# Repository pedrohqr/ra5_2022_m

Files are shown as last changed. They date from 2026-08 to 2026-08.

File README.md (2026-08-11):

# RA5 2022 M — Base Board (Raptor)

Base/carrier board for a modular PLC (Programmable Logic Controller): an I/O
front-end with no main MCU of its own — sensing and metering peripherals are
driven by a separate MCU+LTE modem card that plugs into the onboard M.2
Key-E socket (`J1`, visible in the photos below). The socket follows the M.2
mechanical form factor but uses a custom pinout (native 3.3V logic) — it is
not meant to accept an off-the-shelf M.2 card. The pluggable MCU+modem card
itself now lives in its own separate repository, developed independently
from this base board.

Main blocks on this board:

- **Power**: input via the `B0303S-1W` isolated DC-DC module, `TPS54202DDC`
  buck regulator, `AMS1117-3.3` linear regulator (USB rail), and a USB-C
  connector that passes through to `J1` for flashing/debugging the plugged-in
  MCU card.
- **2x differential 4-20mA analog inputs** via an `ADS1115` I2C ADC.
- **2x digital inputs and 2x digital outputs**, opto/divider-conditioned and
  transistor-driven respectively.
- **`ATM90E32AS` three-phase energy meter**, in a galvanically isolated
  domain (`GND2`/`VDD2`) from the rest of the board, bridged via the
  `ISO7741N1-Y` digital isolator (SPI) and a `CS817X20LS`-family isolator
  (power-mode select).
- **`STM8S003F3P` housekeeping MCU**, reading/driving the digital I/O signals
  and intended to expose them over the shared I2C bus on `J1`.
- `KF250-3.5-2P-2` screw terminals for the current loops and other
  field-side connections.

## Renders of the finished board

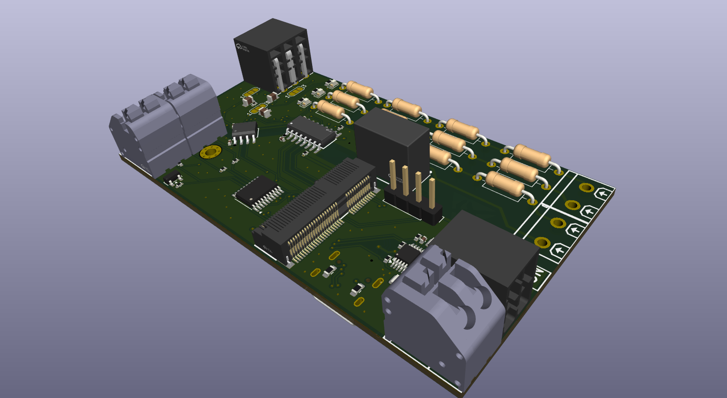
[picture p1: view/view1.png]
Board view 1

*Component-side view: the M.2 socket (`J1`) in the center, screw terminals
and field connectors along the edges, and the row of MOVs/varistors feeding
the energy-meter current inputs.*

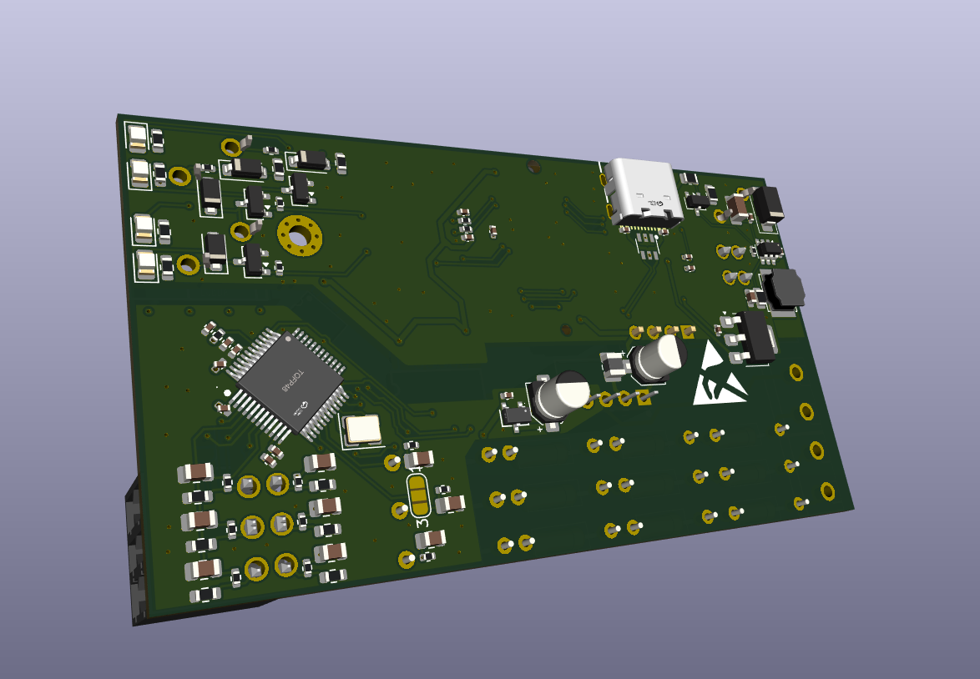
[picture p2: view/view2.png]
Board view 2

*Same side, rotated ~180°, showing the USB-C connector, the STM8
housekeeping MCU, and the power section.*

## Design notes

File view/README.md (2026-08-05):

# RA5 2022 M — Placa Base (Raptor)

Placa base/carrier de um CLP (Controlador Lógico Programável) modular: um
front-end de I/O que não tem MCU principal próprio — os periféricos de
sensoriamento e medição são controlados por um cartão MCU+modem LTE plugado
no soquete M.2 Key-E (`J1`, visível nas fotos), seguindo o padrão mecânico
M.2 mas com pinagem própria (3.3V nativo, sem relação com um cartão M.2 real).

Principais blocos presentes na placa:

- **Alimentação**: entrada via módulo `B0303S-1W`, buck `TPS54202DDC`,
  regulador linear `AMS1117-3.3` (trilho USB) e conector USB-C de
  passthrough para flash/debug do cartão MCU.
- **2x entradas analógicas 4-20mA** (diferenciais) via ADC `ADS1115`.
- **2x entradas e 2x saídas digitais** condicionadas por opto/divisor e
  transistor, respectivamente.
- **Medidor de energia trifásico `ATM90E32AS`**, em domínio galvanicamente
  isolado (`GND2`/`VDD2`) do resto da placa.
- **MCU de housekeeping `STM8S003F3P`**, fazendo a ponte I2C dos sinais de
  I/O digital.
- Terminais parafusáveis `KF250-3.5-2P-2` para os laços de corrente e
  demais conexões de campo.

## Renders da placa finalizada

Vista 1 da placa
*Vista geral do lado dos componentes: soquete M.2 (`J1`), USB-C, terminais
parafusáveis e conectores de campo nas laterais.*

Vista 2 da placa
*Vista girada ~180°, mostrando o mesmo lado a partir do ângulo oposto.*

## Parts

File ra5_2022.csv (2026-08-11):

Reference | Qty | Value | DNP | Exclude from BOM | Exclude from Board | Footprint | JLCPCB Part #
C1 | 1 | 10uF |  |  |  | Capacitor_SMD:C_1206_3216Metric | C13585
C2,C4,C10,C12,C14,C15,C16,C18,C19,C20,C21,C23,C37,C38,C39,C40 | 16 | 100nF |  |  |  | Capacitor_SMD:C_0402_1005Metric | C1525,C307331
C5,C41 | 2 | 10uF |  |  |  | Capacitor_SMD:CP_Elec_4x5.4 | C22383768
C6,C7 | 2 | 22uF |  |  |  | Capacitor_SMD:C_0603_1608Metric | C59461
C8,C11,C13,C22,C42 | 5 | 10uF |  |  |  | Capacitor_SMD:C_0402_1005Metric | C15525
C9 | 1 | 56pF |  |  |  | Capacitor_SMD:C_0603_1608Metric | C39148
C17 | 1 | 1uF |  |  |  | Capacitor_SMD:C_0402_1005Metric | C52923
C24,C25,C26,C27,C28,C29,C31,C32,C33,C34,C35,C36 | 12 | 33nF |  |  |  | Capacitor_SMD:C_0805_2012Metric | C1739
C30 | 1 | 4.7uF |  |  |  | Capacitor_SMD:C_0402_1005Metric | C23733
CN1,CN3,CN4 | 3 | KF250-3.5-2P-2 |  |  |  | ra5_2022:CONN-TH_P3.50_KF250-3.5-2P-2 | C475163
CN2 | 1 | MX15EDGRHC-3.5-2*02P-BK01-CU-A |  |  |  | ra5_2022:CONN-TH_4P-P3.50_JL15EDGRHC-35002B01 | C49142488
D1 | 1 | SS210 |  |  |  | Diode_SMD:D_SMA | C14996
D2,D9,D11,D13,D15 | 5 | LED |  |  |  | LED_SMD:LED_0805_2012Metric | C19171391
D3 | 1 | USBLC6-2SC6 |  |  |  | ra5_2022:SOT-23-6_L2.9-W1.6-P0.95-LS2.8-BL | C7519
D4,D5,D6 | 3 | LED |  |  |  | LED_SMD:LED_0603_1608Metric | C2994781
D7,D8 | 2 | 1N5819WS |  |  |  | Diode_SMD:D_SOD-323 | C191023
D10,D14 | 2 | BZT52C3V3 |  |  |  | Diode_SMD:D_SOD-123 | C216707
D12,D16 | 2 | 1N4004W |  |  |  | Diode_SMD:D_SOD-123F | C162734
J1 | 1 | Bus_M.2_Socket_E |  |  |  | ra5_2022:CONN-SMD_AS0BC21-S48BE-7H | C410527
J3 | 1 | MX15EDGRHC-3.5-2*03P-BK01-Cu-A |  |  |  | ra5_2022:MX15EDGRHC-3.5-2x03P | C49142489
J4 | 1 | MX15EDGKNH-3.5-2*03P-BK01-Cu-A |  |  | Excluded from board |  | C49142469
L1 | 1 | 6.8uH |  |  |  | Inductor_SMD:L_1008_2520Metric | C48533097
L2 | 1 | 10uH |  |  |  | ra5_2022:IND-SMD_L5.0-W5.0-1 | C182189
Q1,Q2,Q3,Q4,Q5 | 5 | BC817-25 |  |  |  | Package_TO_SOT_SMD:SOT-23 | C20069154
R1,R2,R4 | 3 | 100k |  |  |  | Resistor_SMD:R_0805_2012Metric | C149504
R3 | 1 | 150R |  |  |  | Resistor_SMD:R_0603_1608Metric | C22808
R5 | 1 | 22k |  |  |  | Resistor_SMD:R_0402_1005Metric | C25768
R6,R9 | 2 | 4.7k |  |  |  | Resistor_SMD:R_0402_1005Metric | C25900
R7,R8 | 2 | 5.1k |  |  |  | Resistor_SMD:R_0603_1608Metric | C384321
R10,R11 | 2 | 100R |  |  |  | Resistor_SMD:R_0402_1005Metric | C25076
R12,R13,R14,R15,R16,R17,R18,R19,R20,R21,R22,R23 | 12 | 120k |  |  |  | Resistor_THT:R_Axial_DIN0207_L6.3mm_D2.5mm_P10.16mm_Horizontal | C119370
R33,R34,R35,R36,R37,R38,R45,R46,R47,R48,R49,R50,R51,R52 | 14 | 1k |  |  |  | Resistor_SMD:R_0402_1005Metric | C11702
R39,R40,R41,R42,R43,R44 | 6 | 2.4R |  |  |  | Resistor_SMD:R_0603_1608Metric | C2998116
R55,R56,R57,R60,R64,R65,R67,R71,R72,R74 | 10 | 10k |  |  |  | Resistor_SMD:R_0402_1005Metric | C25744
R58,R59 | 2 | 100R |  |  |  | Resistor_SMD:R_1206_3216Metric | C17901
R61,R66,R68,R73,R75,R76,R77 | 7 | 270R |  |  |  | Resistor_SMD:R_0603_1608Metric | C22966
R62,R69 | 2 | 39k |  |  |  | Resistor_SMD:R_0603_1608Metric | C23153
U1 | 1 | STM8S003F3P |  |  |  | Package_SO:TSSOP-20_4.4x6.5mm_P0.65mm | C52717
U2 | 1 | TPS54202DDC |  |  |  | Package_TO_SOT_SMD:SOT-23-6 | C191884
U3 | 1 | B0303S-1WR2 |  |  |  | ra5_2022:PWRM-TH_BXXXXS-1WR2 | C7598619
U4 | 1 | XC6206P332MR-JSM |  |  |  | ra5_2022:SOT-23-3_L3.0-W1.7-P0.95-LS2.9-BR | C20616640
U5 | 1 | ISO7741N1-Y |  |  |  | ra5_2022:SOIC-16_L9.9-W3.9-P1.27-LS6.0-BL-1 | C53446593
U6 | 1 | CA-IS3720CLS |  |  |  | ra5_2022:SOIC-8_L4.9-W3.9-P1.27-LS6.0-BL | C41784134
U7 | 1 | AMS1117-3.3 |  |  |  | Package_TO_SOT_SMD:SOT-223-3_TabPin2 | C50313802
U8,U9 | 2 | DB126V-5.0-2P-BK-P |  |  |  | ra5_2022:CONN-TH_2P-P5.00_DIBO_DB126V-5.0-2P-BU-P | C49260677
U10 | 1 | ATM90E32AS-AU-R |  |  |  | ra5_2022:TQFP-48_L7.0-W7.0-P0.50-LS9.0-BL | C177153
U12 | 1 | ADS1115IDGS |  |  |  | Package_SO:TSSOP-10_3x3mm_P0.5mm | C37593
USB1 | 1 | HYCW498-USBC16-735B |  |  |  | ra5_2022:USB-C-SMD_HYCW498-USBC16-735B | C42400252
Y1 | 1 | ABM8G-16.384MHZ-18-D2Y-T |  |  |  | Crystal:Crystal_SMD_3225-4Pin_3.2x2.5mm | C7065080

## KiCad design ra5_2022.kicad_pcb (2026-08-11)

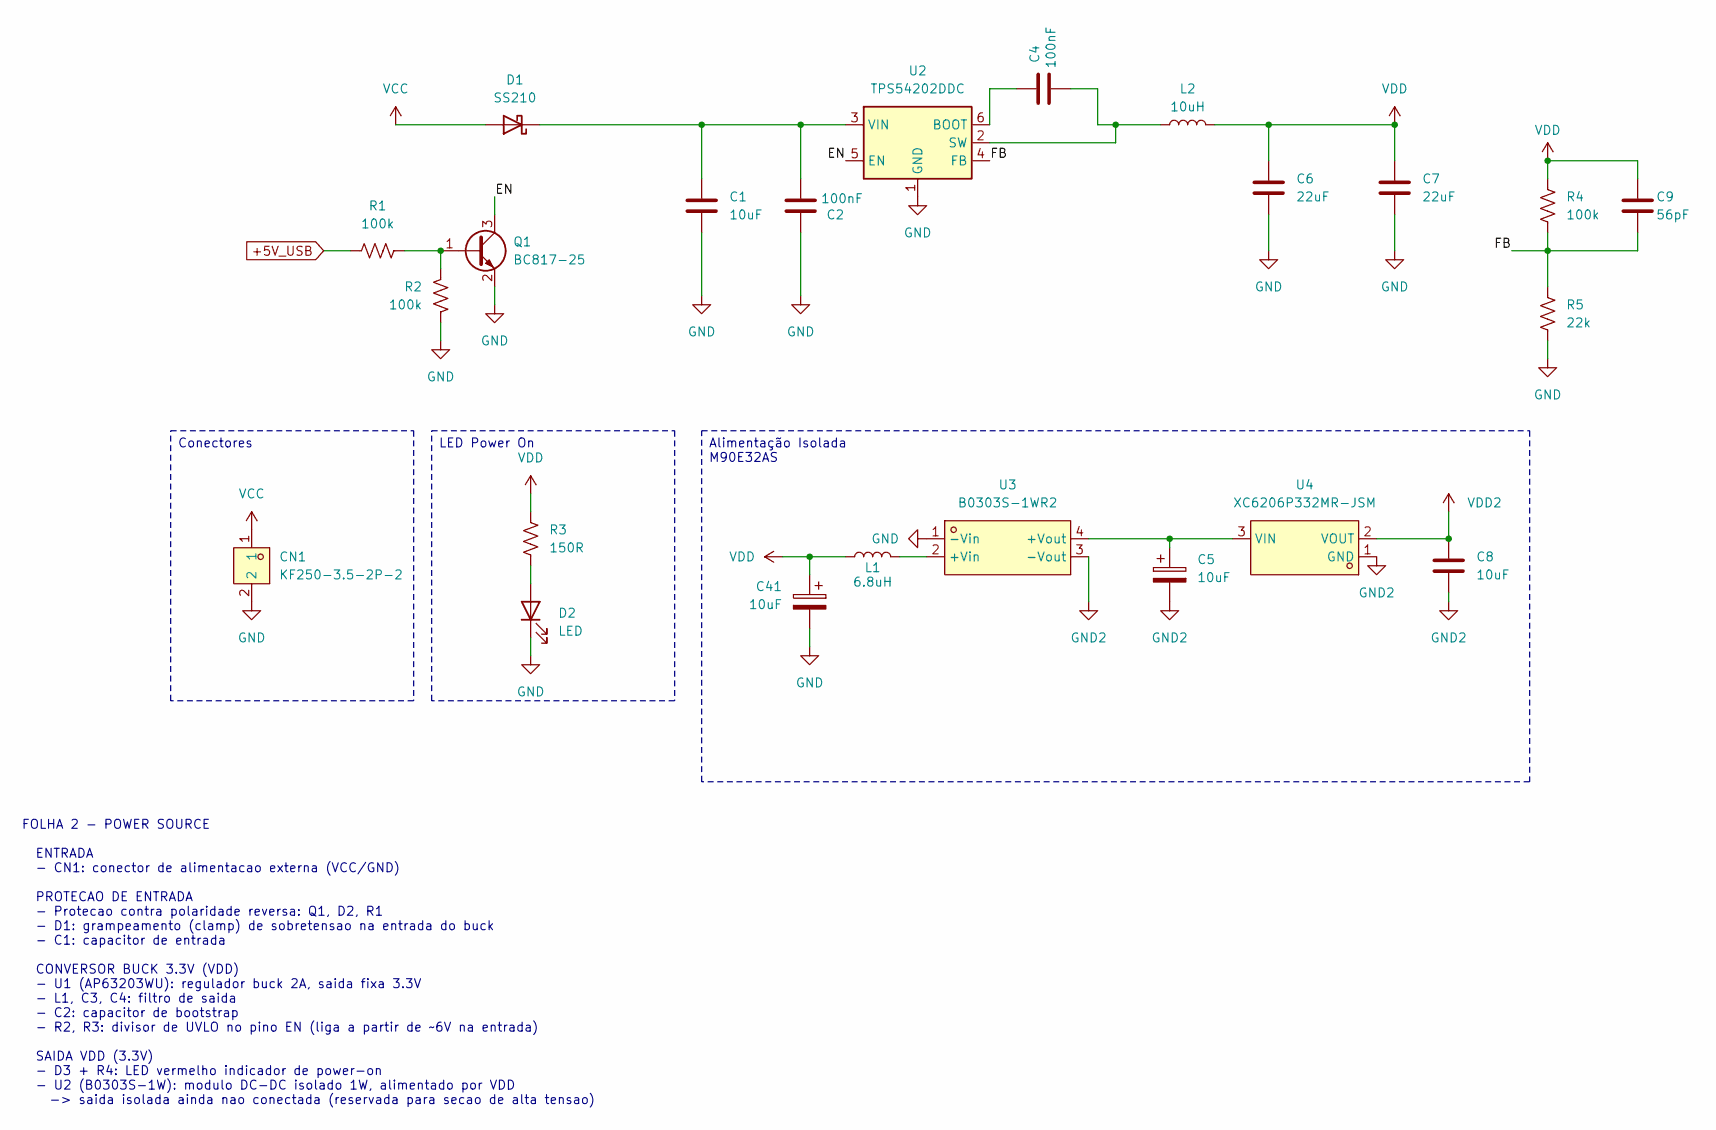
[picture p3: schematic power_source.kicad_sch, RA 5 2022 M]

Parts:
C1: 10uF; C_1206_3216Metric; MPN CL31A106KBHNNNE; JLCPCB Part # C13585
C2: 100nF; C_0402_1005Metric; MPN CL05B104KB54PNC; JLCPCB Part # C307331
C4: 100nF; C_0402_1005Metric; MPN CL05B104KO5NNNC; JLCPCB Part # C1525
C5, C41: 10uF; CP_Elec_4x5.4; MPN VT1E100M0405; JLCPCB Part # C22383768
C6, C7: 22uF; C_0603_1608Metric; MPN CL10A226MQ8NRNC; JLCPCB Part # C59461
C8: 10uF; C_0402_1005Metric; MPN CL05A106MQ5NUNC; JLCPCB Part # C15525
C9: 56pF; C_0603_1608Metric; MPN CL10C560JB8NNNC; JLCPCB Part # C39148
CN1: KF250-3.5-2P-2; CONN-TH_P3.50_KF250-3.5-2P-2; MPN KF250-3.5-2P-2; JLCPCB Part # C475163
D1: SS210; D_SMA; MPN SS210; JLCPCB Part # C14996
D2: LED; LED_0805_2012Metric; MPN YLED0805R; JLCPCB Part # C19171391
L1: 6.8uH; L_1008_2520Metric; MPN SLW252010S6R8MST; JLCPCB Part # C48533097
L2: 10uH; IND-SMD_L5.0-W5.0-1; MPN SLW5040S100MST; JLCPCB Part # C182189
Q1: BC817-25; SOT-23; MPN BC817-25; JLCPCB Part # C20069154
R1, R2, R4: 100k; R_0805_2012Metric; MPN 0805W8F1003T5E; JLCPCB Part # C149504
R3: 150R; R_0603_1608Metric; MPN 0603WAF1500T5E; JLCPCB Part # C22808
R5: 22k; R_0402_1005Metric; MPN 0402WGF2202TCE; JLCPCB Part # C25768
U2: TPS54202DDC; SOT-23-6; MPN TPS54202DDCR; JLCPCB Part # C191884
U3: B0303S-1WR2; PWRM-TH_BXXXXS-1WR2; MPN B0303S-1WR2; JLCPCB Part # C7598619
U4: XC6206P332MR-JSM; SOT-23-3_L3.0-W1.7-P0.95-LS2.9-BR; MPN XC6206P332MR-JSM; JLCPCB Part # C20616640

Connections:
+5V_USB: R1.1; also elsewhere on the board
/Power Source/EN: Q1.3 (C), U2.5 (EN)
/Power Source/FB: C9.2, R4.1, R5.1, U2.4 (FB)
GND: C1.2, C2.1, C6.2, C7.2, C41.2, CN1.2, D2.1 (K), Q1.2 (E), R2.1, R5.2, U2.1 (GND), U3.1 (-Vin); also elsewhere on the board
GND2: C5.2, C8.2, U3.3 (-Vout), U4.1 (GND); also elsewhere on the board
unnamed: C1.1, C2.2, D1.1 (K), U2.3 (VIN)
unnamed: D2.2 (A), R3.2
unnamed: Q1.1 (B), R1.2, R2.2
unnamed: C4.1, U2.6 (BOOT)
unnamed: C4.2, L2.1, U2.2 (SW)
unnamed: L1.2, U3.2 (+Vin)
unnamed: C5.1, U3.4 (+Vout), U4.3 (VIN)
VCC: CN1.1, D1.2 (A)
VDD: C6.1, C7.1, C9.1, C41.1, L1.1, L2.2, R3.1, R4.2; also elsewhere on the board
VDD2: C8.1, U4.2 (VOUT); also elsewhere on the board

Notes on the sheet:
FOLHA 2 - POWER SOURCE ENTRADA - CN1: conector de alimentacao externa (VCC/GND) PROTECAO DE ENTRADA - Protecao contra polaridade reversa: Q1, D2, R1 - D1: grampeamento (clamp) de sobretensao na entrada do buck - C1: capacitor de entrada CONVERSOR BUCK 3.3V (VDD) - U1 (AP63203WU): regulador buck 2A,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
Conectores
Alimentação Isolada M90E32AS
LED Power On

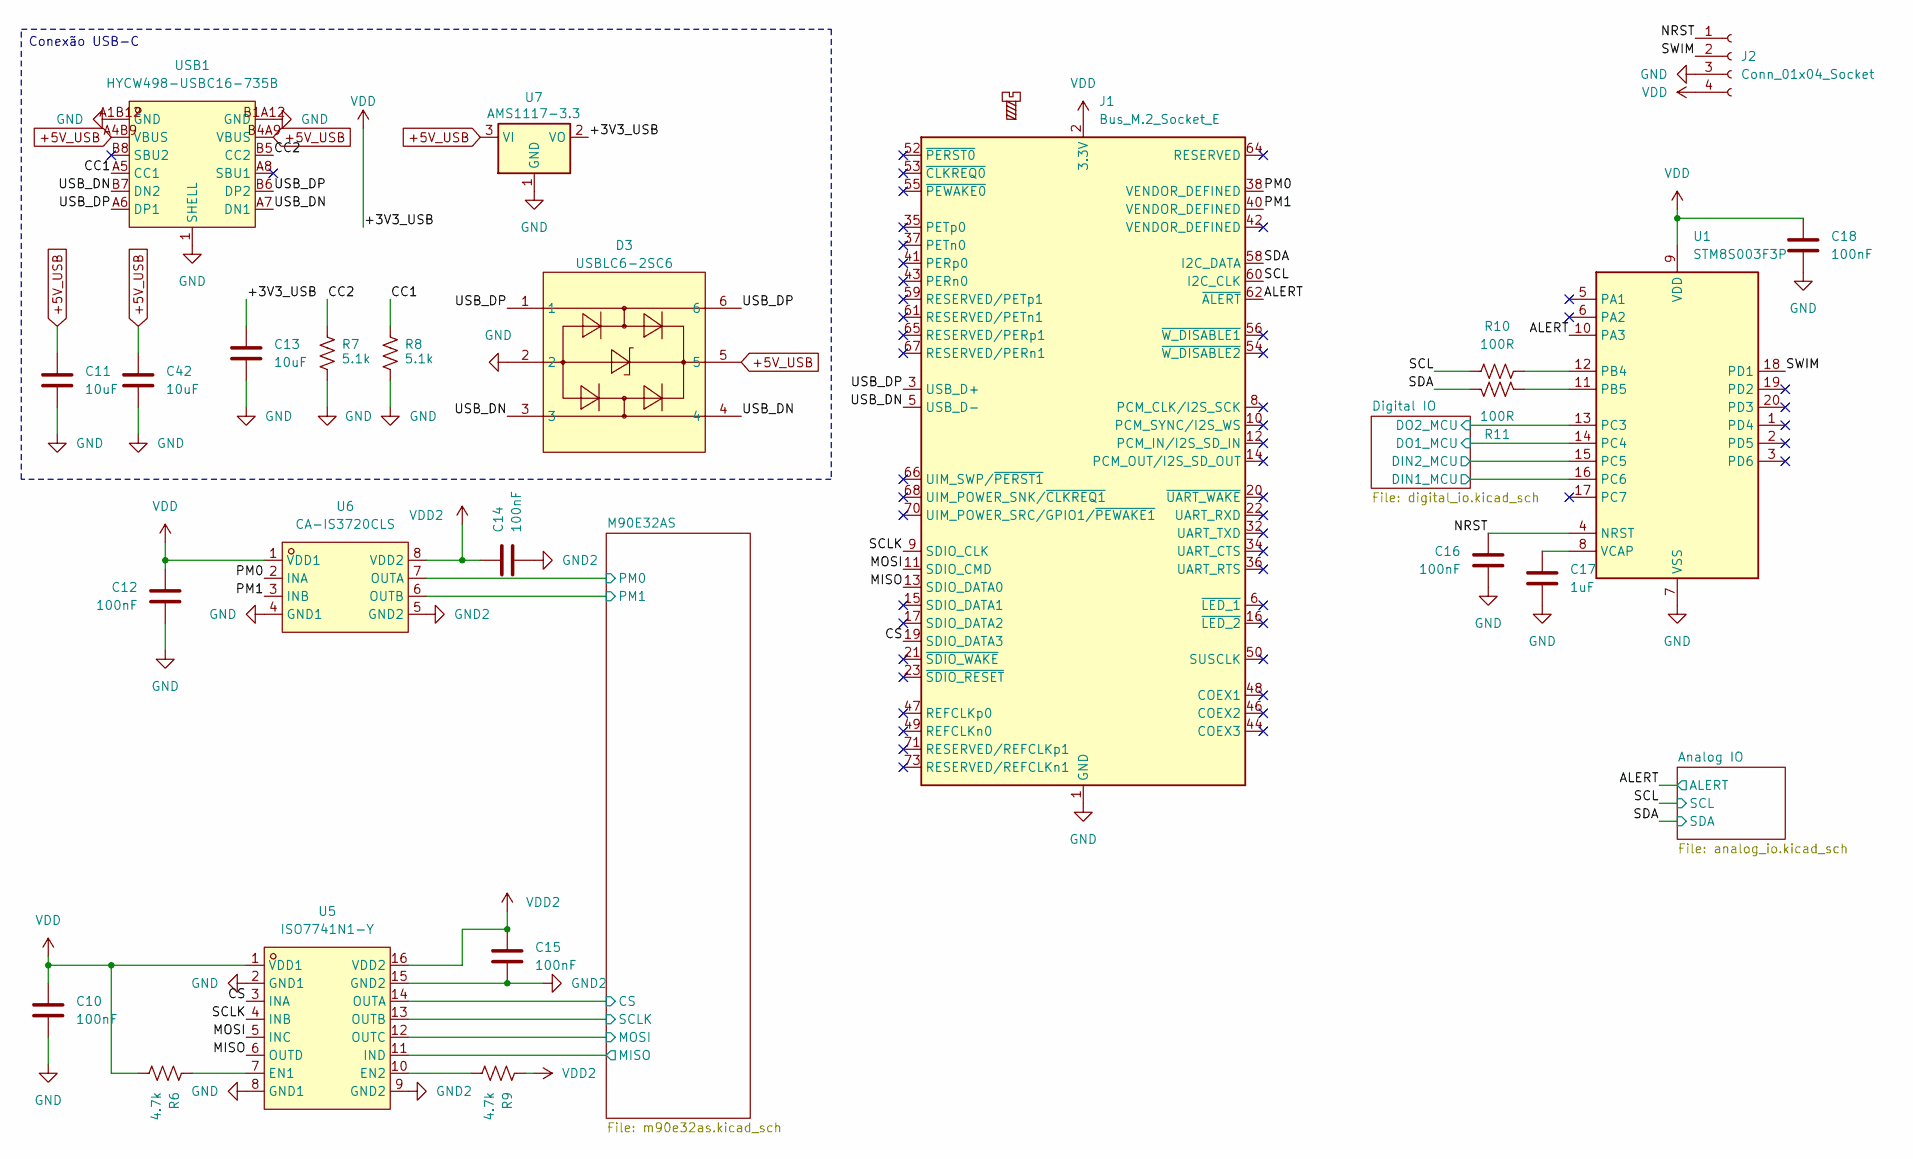
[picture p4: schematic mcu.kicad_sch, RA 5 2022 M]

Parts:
C10, C12, C14, C15, C16, C18: 100nF; C_0402_1005Metric; MPN CL05B104KO5NNNC; JLCPCB Part # C1525
C11, C13, C42: 10uF; C_0402_1005Metric; MPN CL05A106MQ5NUNC; JLCPCB Part # C15525
C17: 1uF; C_0402_1005Metric; MPN CL05A105KA5NQNC; JLCPCB Part # C52923
D3: USBLC6-2SC6; SOT-23-6_L2.9-W1.6-P0.95-LS2.8-BL; MPN USBLC6-2SC6; JLCPCB Part # C7519
H1: MountingScrew; MountingHole_2.2mm_M2_Pad_Via
J1: Bus_M.2_Socket_E; CONN-SMD_AS0BC21-S48BE-7H; MPN AS0BC21-S40BE-7H; JLCPCB Part # C410527
J2: Conn_01x04_Socket; PinHeader_1x04_P2.54mm_Vertical
R6, R9: 4.7k; R_0402_1005Metric; MPN 0402WGF4701TCE; JLCPCB Part # C25900
R7, R8: 5.1k; R_0603_1608Metric; MPN WR04X512JTL; JLCPCB Part # C384321
R10, R11: 100R; R_0402_1005Metric; MPN 0402WGF1000TCE; JLCPCB Part # C25076
U1: STM8S003F3P; TSSOP-20_4.4x6.5mm_P0.65mm; MPN STM8S003F3P6TR; JLCPCB Part # C52717
U5: ISO7741N1-Y; SOIC-16_L9.9-W3.9-P1.27-LS6.0-BL-1; MPN ISO7741N1-Y; JLCPCB Part # C53446593
U6: CA-IS3720CLS; SOIC-8_L4.9-W3.9-P1.27-LS6.0-BL; MPN CA-IS3720CLS; JLCPCB Part # C41784134
U7: AMS1117-3.3; SOT-223-3_TabPin2; MPN AMS1117-3.3OF; JLCPCB Part # C50313802
USB1: HYCW498-USBC16-735B; USB-C-SMD_HYCW498-USBC16-735B; MPN HYCW498-USBC16-735B; JLCPCB Part # C42400252

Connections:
+5V_USB: C11.1, C42.1, D3.5, U7.3 (VI), USB1.A4B9 (VBUS), USB1.B4A9 (VBUS); also elsewhere on the board
/MCU/ALERT: J1.62 (~ALERT), U1.10 (PA3); also elsewhere on the board
/MCU/CC1: R8.2, USB1.A5 (CC1)
/MCU/CC2: R7.2, USB1.B5 (CC2)
/MCU/CS: J1.19 (SDIO_DATA3), U5.3 (INA)
/MCU/Digital IO/DIN1_MCU: U1.16 (PC6); also elsewhere on the board
/MCU/Digital IO/DIN2_MCU: U1.15 (PC5); also elsewhere on the board
/MCU/Digital IO/DO1_MCU: U1.14 (PC4); also elsewhere on the board
/MCU/Digital IO/DO2_MCU: U1.13 (PC3); also elsewhere on the board
/MCU/M90E32AS/CS: U5.14 (OUTA); also elsewhere on the board
/MCU/M90E32AS/MISO: U5.11 (IND); also elsewhere on the board
/MCU/M90E32AS/MOSI: U5.12 (OUTC); also elsewhere on the board
/MCU/M90E32AS/PM0: U6.7 (OUTA); also elsewhere on the board
/MCU/M90E32AS/PM1: U6.6 (OUTB); also elsewhere on the board
/MCU/M90E32AS/SCLK: U5.13 (OUTB); also elsewhere on the board
/MCU/MISO: J1.13 (SDIO_DATA0), U5.6 (OUTD)
/MCU/MOSI: J1.11 (SDIO_CMD), U5.5 (INC)
/MCU/NRST: C16.1, J2.1, U1.4 (NRST)
/MCU/PM0: J1.38 (VENDOR_DEFINED), U6.2 (INA)
/MCU/PM1: J1.40 (VENDOR_DEFINED), U6.3 (INB)
/MCU/SCL: J1.60 (I2C_CLK), R10.1; also elsewhere on the board
/MCU/SCLK: J1.9 (SDIO_CLK), U5.4 (INB)
/MCU/SDA: J1.58 (I2C_DATA), R11.1; also elsewhere on the board
/MCU/SWIM: J2.2, U1.18 (PD1)
GND: C10.2, C11.2, C12.2, C13.2, C16.2, C17.2, C18.2, C42.2, D3.2, J1.1 (GND), J1.7 (GND), J1.18 (GND), J1.33 (GND), J1.39 (GND), J1.45 (GND), J1.51 (GND), J1.57 (GND), J1.63 (GND), J1.69 (GND), J1.75 (GND), J2.3, R7.1, R8.1, U1.7 (VSS), U5.2 (GND1), U5.8 (GND1), U6.4 (GND1), U7.1 (GND), USB1.1 (SHELL), USB1.A1B12 (GND), USB1.B1A12 (GND); also elsewhere on the board
GND2: C14.2, C15.2, U5.9 (GND2), U5.15 (GND2), U6.5 (GND2); also elsewhere on the board
unnamed: R10.2, U1.12 (PB4)
unnamed: R11.2, U1.11 (PB5)
unnamed: C17.1, U1.8 (VCAP)
unnamed: R6.2, U5.7 (EN1)
unnamed: R9.1, U5.10 (EN2)
VDD: C10.1, C12.1, C13.1, C18.1, J1.2 (3.3V), J1.4 (3.3V), J1.72 (3.3V), J1.74 (3.3V), J2.4, R6.1, U1.9 (VDD), U5.1 (VDD1), U6.1 (VDD1), U7.2 (VO); also elsewhere on the board
VDD2: C14.1, C15.1, R9.2, U5.16 (VDD2), U6.8 (VDD2); also elsewhere on the board

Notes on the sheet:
Conexão USB-C

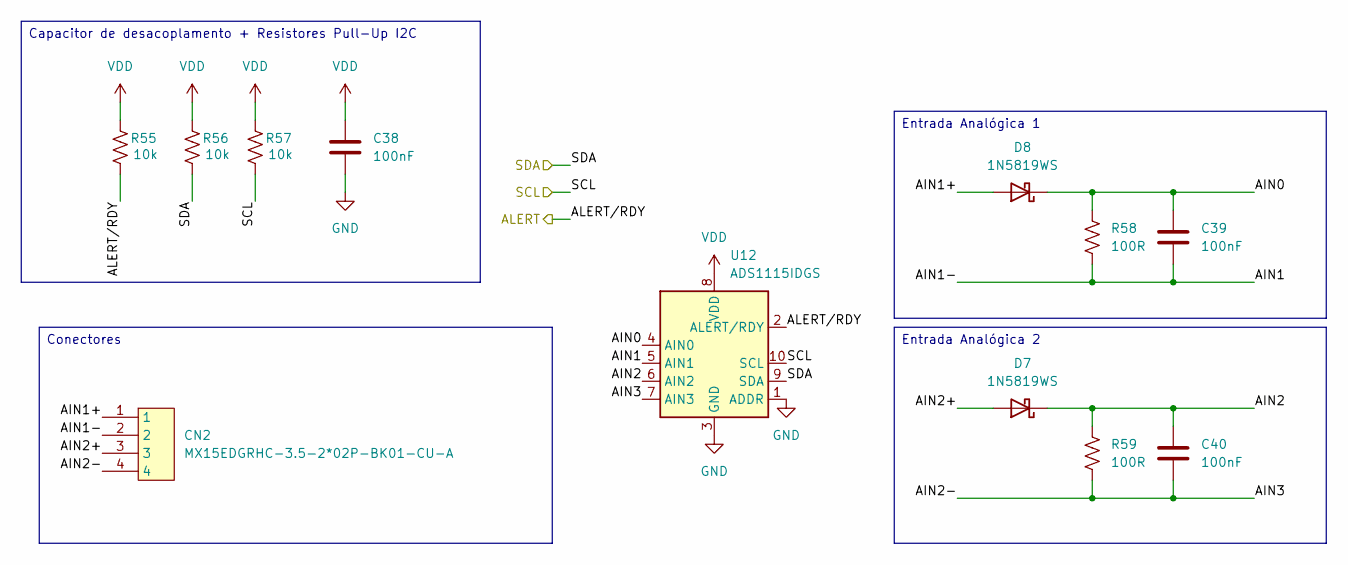
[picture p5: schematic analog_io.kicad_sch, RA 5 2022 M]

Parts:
C38, C39, C40: 100nF; C_0402_1005Metric; MPN CL05B104KO5NNNC; JLCPCB Part # C1525
CN2: MX15EDGRHC-3.5-2*02P-BK01-CU-A; CONN-TH_4P-P3.50_JL15EDGRHC-35002B01; MPN MX15EDGRHC-3.5-2*02P-BK01-Cu-A; JLCPCB Part # C49142488
D7, D8: 1N5819WS; D_SOD-323; MPN 1N5819WS; JLCPCB Part # C191023
R55, R56, R57: 10k; R_0402_1005Metric; MPN 0402WGF1002TCE; JLCPCB Part # C25744
R58, R59: 100R; R_1206_3216Metric; MPN 1206W4F1000T5E; JLCPCB Part # C17901
U12: ADS1115IDGS; TSSOP-10_3x3mm_P0.5mm; MPN ADS1115IDGSR; JLCPCB Part # C37593

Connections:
/MCU/ALERT: R55.1, U12.2 (ALERT/RDY); also elsewhere on the board
/MCU/Analog IO/AIN0: C39.1, D8.1 (K), R58.1, U12.4 (AIN0)
/MCU/Analog IO/AIN1: C39.2, CN2.2, R58.2, U12.5 (AIN1)
/MCU/Analog IO/AIN1+: CN2.1, D8.2 (A)
/MCU/Analog IO/AIN2: C40.1, D7.1 (K), R59.1, U12.6 (AIN2)
/MCU/Analog IO/AIN2+: CN2.3, D7.2 (A)
/MCU/Analog IO/AIN2-: C40.2, CN2.4, R59.2, U12.7 (AIN3)
/MCU/SCL: R57.1, U12.10 (SCL); also elsewhere on the board
/MCU/SDA: R56.1, U12.9 (SDA); also elsewhere on the board
GND: C38.2, U12.1 (ADDR), U12.3 (GND); also elsewhere on the board
VDD: C38.1, R55.2, R56.2, R57.2, U12.8 (VDD); also elsewhere on the board

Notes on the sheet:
Capacitor de desacoplamento + Resistores Pull-Up I2C
Conectores
Entrada Analógica 2
Entrada Analógica 1

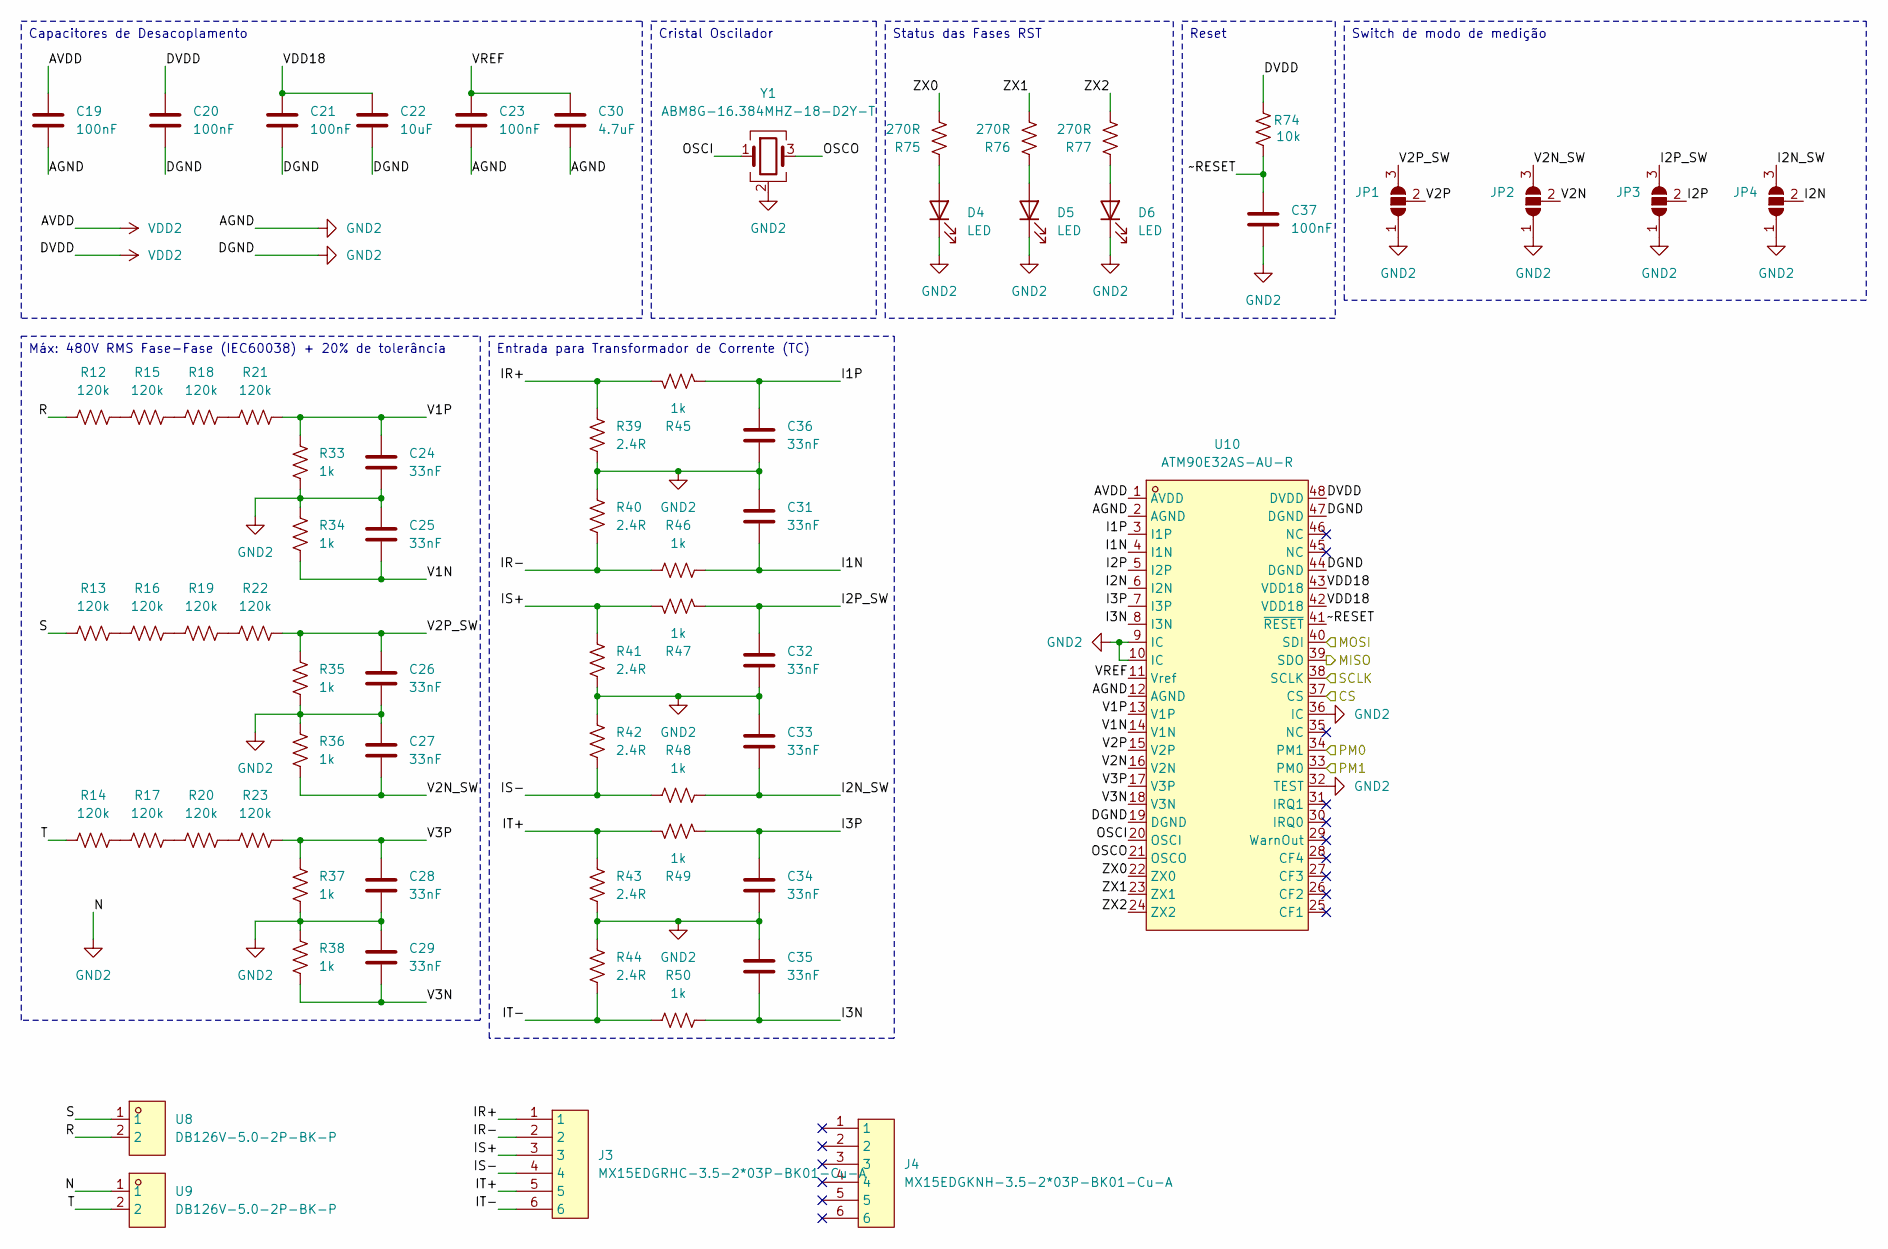
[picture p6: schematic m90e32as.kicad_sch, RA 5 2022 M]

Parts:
C19, C20, C21, C23, C37: 100nF; C_0402_1005Metric; MPN CL05B104KO5NNNC; JLCPCB Part # C1525
C22: 10uF; C_0402_1005Metric; MPN CL05A106MQ5NUNC; JLCPCB Part # C15525
C24, C25, C26, C27, C28, C29, C31, C32, C33, C34, C35, C36: 33nF; C_0805_2012Metric; MPN 0805B333K500NT; JLCPCB Part # C1739
C30: 4.7uF; C_0402_1005Metric; MPN CL05A475MP5NRNC; JLCPCB Part # C23733
D4, D5, D6: LED; LED_0603_1608Metric; MPN 19-219/GHC-YR2T1B5Y/3T; JLCPCB Part # C2994781
J3: MX15EDGRHC-3.5-2*03P-BK01-Cu-A; MX15EDGRHC-3.5-2x03P; MPN MX15EDGRHC-3.5-2*03P-BK01-Cu-A; JLCPCB Part # C49142489
J4: MX15EDGKNH-3.5-2*03P-BK01-Cu-A; MPN MX15EDGKNH-3.5-2*03P-BK01-Cu-A; JLCPCB Part # C49142469
JP1, JP2, JP3, JP4: SolderJumper_3_Open; SolderJumper-3_P1.3mm_Open_RoundedPad1.0x1.5mm_NumberLabels
R12, R13, R14, R15, R16, R17, R18, R19, R20, R21, R22, R23: 120k; R_Axial_DIN0207_L6.3mm_D2.5mm_P10.16mm_Horizontal; MPN MF1/4W-120KΩ±1% T; JLCPCB Part # C119370
R33, R34, R35, R36, R37, R38, R45, R46, R47, R48, R49, R50: 1k; R_0402_1005Metric; MPN 0402WGF1001TCE; JLCPCB Part # C11702
R39, R40, R41, R42, R43, R44: 2.4R; R_0603_1608Metric; MPN FRC0603F2R40TS; JLCPCB Part # C2998116
R74: 10k; R_0402_1005Metric; MPN 0402WGF1002TCE; JLCPCB Part # C25744
R75, R76, R77: 270R; R_0603_1608Metric; MPN 0603WAF2700T5E; JLCPCB Part # C22966
U8, U9: DB126V-5.0-2P-BK-P; CONN-TH_2P-P5.00_DIBO_DB126V-5.0-2P-BU-P; MPN DB126V-5.0-2P-BK-P; JLCPCB Part # C49260677
U10: ATM90E32AS-AU-R; TQFP-48_L7.0-W7.0-P0.50-LS9.0-BL; MPN ATM90E32AS-AU-R; JLCPCB Part # C177153
Y1: ABM8G-16.384MHZ-18-D2Y-T; Crystal_SMD_3225-4Pin_3.2x2.5mm; MPN ABM8G-16.384MHZ-18-D2Y-T; JLCPCB Part # C7065080

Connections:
/MCU/M90E32AS/CS: U10.37 (CS); also elsewhere on the board
/MCU/M90E32AS/I1N: C31.2, R46.2, U10.4 (I1N)
/MCU/M90E32AS/I1P: C36.1, R45.2, U10.3 (I1P)
/MCU/M90E32AS/I2N: JP4.2 (C), U10.6 (I2N)
/MCU/M90E32AS/I2N_SW: C33.2, JP4.3 (B), R48.2
/MCU/M90E32AS/I2P: JP3.2 (C), U10.5 (I2P)
/MCU/M90E32AS/I2P_SW: C32.1, JP3.3 (B), R47.2
/MCU/M90E32AS/I3N: C35.2, R50.2, U10.8 (I3N)
/MCU/M90E32AS/I3P: C34.1, R49.2, U10.7 (I3P)
/MCU/M90E32AS/IR+: J3.1, R39.1, R45.1
/MCU/M90E32AS/IR-: J3.2, R40.2, R46.1
/MCU/M90E32AS/IS+: J3.3, R41.1, R47.1
/MCU/M90E32AS/IS-: J3.4, R42.2, R48.1
/MCU/M90E32AS/IT+: J3.5, R43.1, R49.1
/MCU/M90E32AS/IT-: J3.6, R44.2, R50.1
/MCU/M90E32AS/MISO: U10.39 (SDO); also elsewhere on the board
/MCU/M90E32AS/MOSI: U10.40 (SDI); also elsewhere on the board
/MCU/M90E32AS/OSCI: U10.20 (OSCI), Y1.1
/MCU/M90E32AS/OSCO: U10.21 (OSCO), Y1.3
/MCU/M90E32AS/PM0: U10.34 (PM1); also elsewhere on the board
/MCU/M90E32AS/PM1: U10.33 (PM0); also elsewhere on the board
/MCU/M90E32AS/R: R12.1, U8.2
/MCU/M90E32AS/S: R13.1, U8.1
/MCU/M90E32AS/SCLK: U10.38 (SCLK); also elsewhere on the board
/MCU/M90E32AS/T: R14.1, U9.2
/MCU/M90E32AS/V1N: C25.2, R34.2, U10.14 (V1N)
/MCU/M90E32AS/V1P: C24.1, R21.2, R33.1, U10.13 (V1P)
/MCU/M90E32AS/V2N: JP2.2 (C), U10.16 (V2N)
/MCU/M90E32AS/V2N_SW: C27.2, JP2.3 (B), R36.2
/MCU/M90E32AS/V2P: JP1.2 (C), U10.15 (V2P)
/MCU/M90E32AS/V2P_SW: C26.1, JP1.3 (B), R22.2, R35.1
/MCU/M90E32AS/V3N: C29.2, R38.2, U10.18 (V3N)
/MCU/M90E32AS/V3P: C28.1, R23.2, R37.1, U10.17 (V3P)
/MCU/M90E32AS/VDD18: C21.1, C22.1, U10.42 (VDD18), U10.43 (VDD18)
/MCU/M90E32AS/VREF: C23.1, C30.1, U10.11 (Vref)
/MCU/M90E32AS/ZX0: R75.1, U10.22 (ZX0)
/MCU/M90E32AS/ZX1: R76.1, U10.23 (ZX1)
/MCU/M90E32AS/ZX2: R77.1, U10.24 (ZX2)
/MCU/M90E32AS/~RESET: C37.1, R74.1, U10.41 (~RESET)
GND2: C19.2, C20.2, C21.2, C22.2, C23.2, C24.2, C25.1, C26.2, C27.1, C28.2, C29.1, C30.2, C31.1, C32.2, C33.1, C34.2, C35.1, C36.2, C37.2, D4.1 (K), D5.1 (K), D6.1 (K), JP1.1 (A), JP2.1 (A), JP3.1 (A), JP4.1 (A), R33.2, R34.1, R35.2, R36.1, R37.2, R38.1, R39.2, R40.1, R41.2, R42.1, R43.2, R44.1, U9.1, U10.2 (AGND), U10.9 (IC), U10.10 (IC), U10.12 (AGND), U10.19 (DGND), U10.32 (TEST), U10.36 (IC), U10.44 (DGND), U10.47 (DGND), Y1.2 (G), Y1.4 (G); also elsewhere on the board
unnamed: D4.2 (A), R75.2
unnamed: D5.2 (A), R76.2
unnamed: D6.2 (A), R77.2
unnamed: R12.2, R15.1
unnamed: R13.2, R16.1
unnamed: R14.2, R17.1
unnamed: R15.2, R18.1
unnamed: R16.2, R19.1
unnamed: R17.2, R20.1
unnamed: R18.2, R21.1
unnamed: R19.2, R22.1
unnamed: R20.2, R23.1
VDD2: C19.1, C20.1, R74.2, U10.1 (AVDD), U10.48 (DVDD); also elsewhere on the board

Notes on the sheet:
Capacitores de Desacoplamento
Cristal Oscilador
Reset
Entrada para Transformador de Corrente (TC)
Máx: 480V RMS Fase-Fase (IEC60038) + 20% de tolerância
Status das Fases RST
Switch de modo de medição

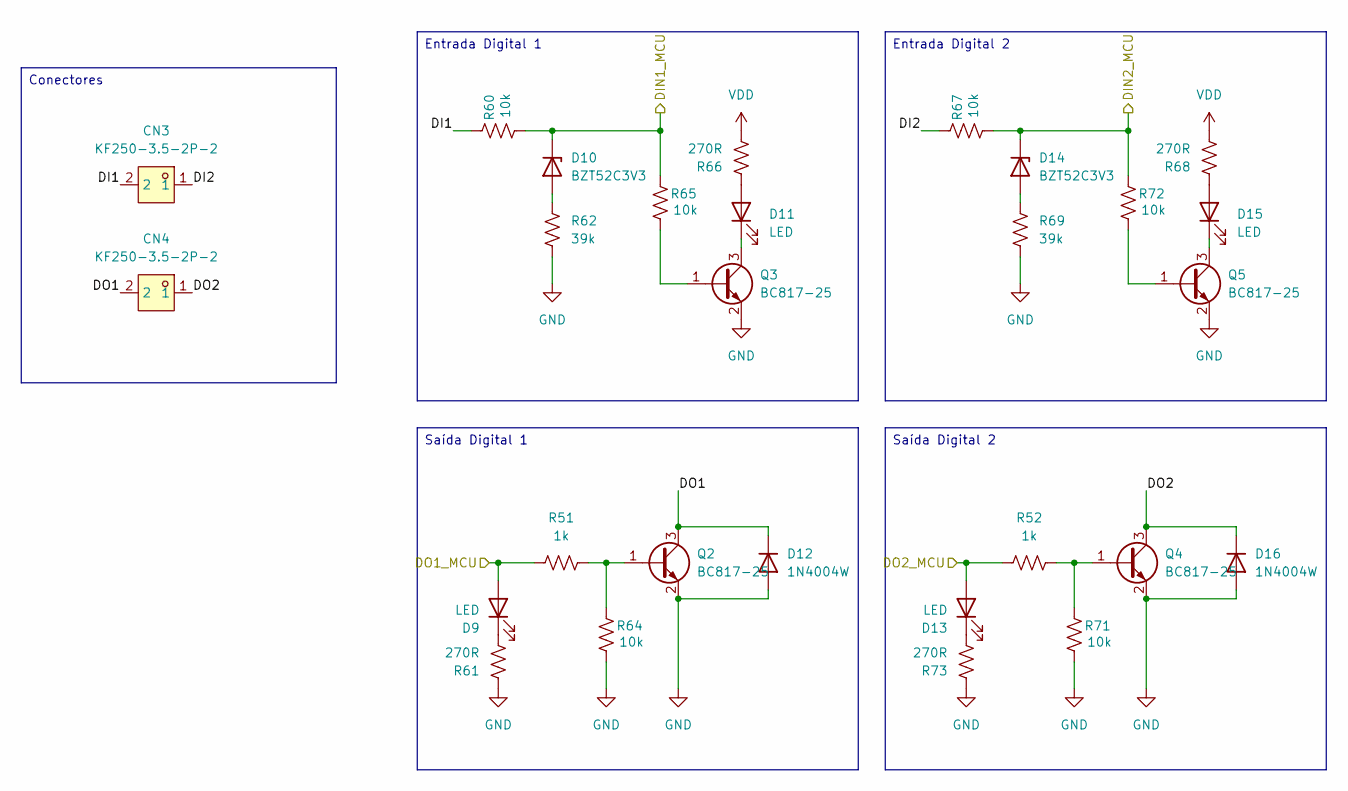
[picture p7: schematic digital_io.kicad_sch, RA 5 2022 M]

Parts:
CN3, CN4: KF250-3.5-2P-2; CONN-TH_P3.50_KF250-3.5-2P-2; MPN KF250-3.5-2P-2; JLCPCB Part # C475163
D9, D11, D13, D15: LED; LED_0805_2012Metric; MPN YLED0805R; JLCPCB Part # C19171391
D10, D14: BZT52C3V3; D_SOD-123; MPN BZT52C3V3; JLCPCB Part # C216707
D12, D16: 1N4004W; D_SOD-123F; MPN 1N4004W; JLCPCB Part # C162734
Q2, Q3, Q4, Q5: BC817-25; SOT-23; MPN BC817-25; JLCPCB Part # C20069154
R51, R52: 1k; R_0402_1005Metric; MPN 0402WGF1001TCE; JLCPCB Part # C11702
R60, R64, R65, R67, R71, R72: 10k; R_0402_1005Metric; MPN 0402WGF1002TCE; JLCPCB Part # C25744
R61, R66, R68, R73: 270R; R_0603_1608Metric; MPN 0603WAF2700T5E; JLCPCB Part # C22966
R62, R69: 39k; R_0603_1608Metric; MPN 0603WAF3902T5E; JLCPCB Part # C23153

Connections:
/MCU/Digital IO/DI1: CN3.2, R60.2
/MCU/Digital IO/DI2: CN3.1, R67.2
/MCU/Digital IO/DIN1_MCU: D10.1 (K), R60.1, R65.2; also elsewhere on the board
/MCU/Digital IO/DIN2_MCU: D14.1 (K), R67.1, R72.2; also elsewhere on the board
/MCU/Digital IO/DO1: CN4.2, D12.1 (K), Q2.3 (C)
/MCU/Digital IO/DO1_MCU: D9.2 (A), R51.1; also elsewhere on the board
/MCU/Digital IO/DO2: CN4.1, D16.1 (K), Q4.3 (C)
/MCU/Digital IO/DO2_MCU: D13.2 (A), R52.1; also elsewhere on the board
GND: D12.2 (A), D16.2 (A), Q2.2 (E), Q3.2 (E), Q4.2 (E), Q5.2 (E), R61.2, R62.1, R64.1, R69.1, R71.1, R73.2; also elsewhere on the board
unnamed: D9.1 (K), R61.1
unnamed: D10.2 (A), R62.2
unnamed: D11.2 (A), R66.2
unnamed: D11.1 (K), Q3.3 (C)
unnamed: D13.1 (K), R73.1
unnamed: D14.2 (A), R69.2
unnamed: D15.2 (A), R68.2
unnamed: D15.1 (K), Q5.3 (C)
unnamed: Q2.1 (B), R51.2, R64.2
unnamed: Q3.1 (B), R65.1
unnamed: Q4.1 (B), R52.2, R71.2
unnamed: Q5.1 (B), R72.1
VDD: R66.1, R68.1; also elsewhere on the board

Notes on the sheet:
Saída Digital 1
Entrada Digital 2
Saída Digital 2
Conectores
Entrada Digital 1

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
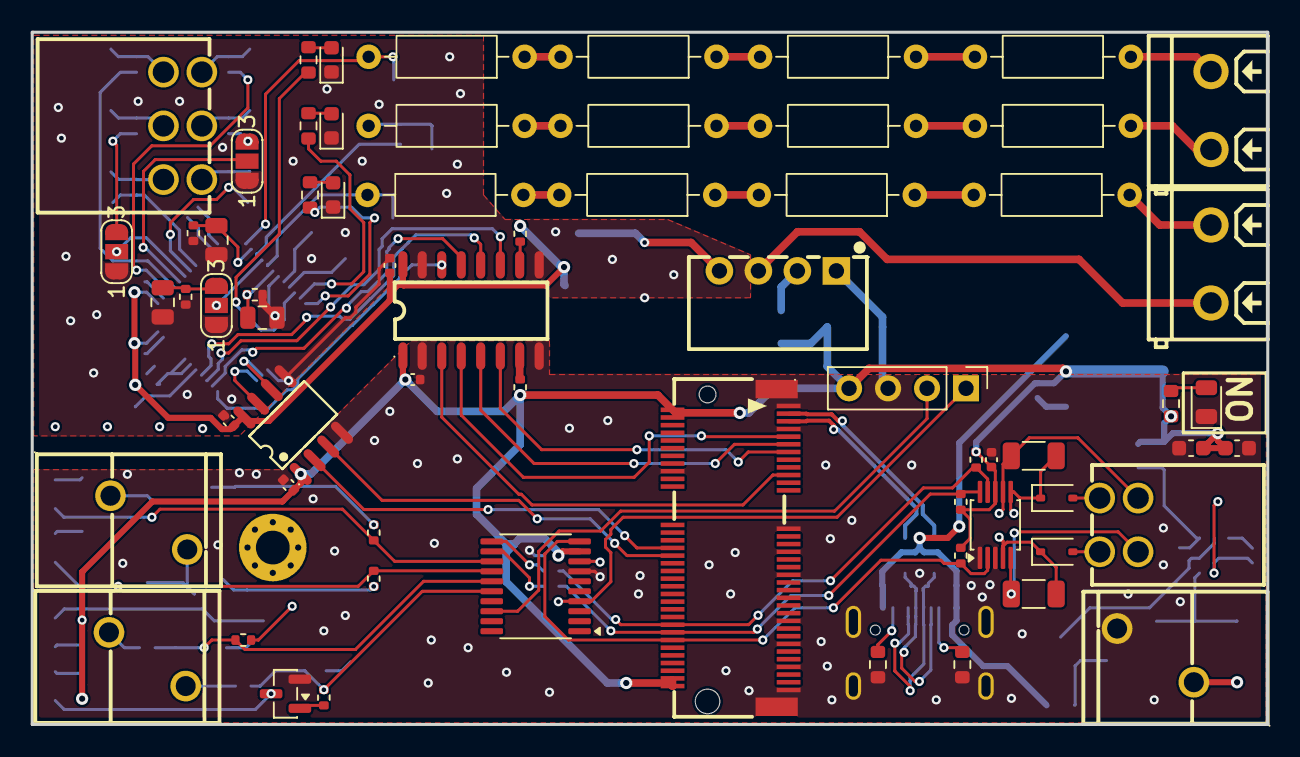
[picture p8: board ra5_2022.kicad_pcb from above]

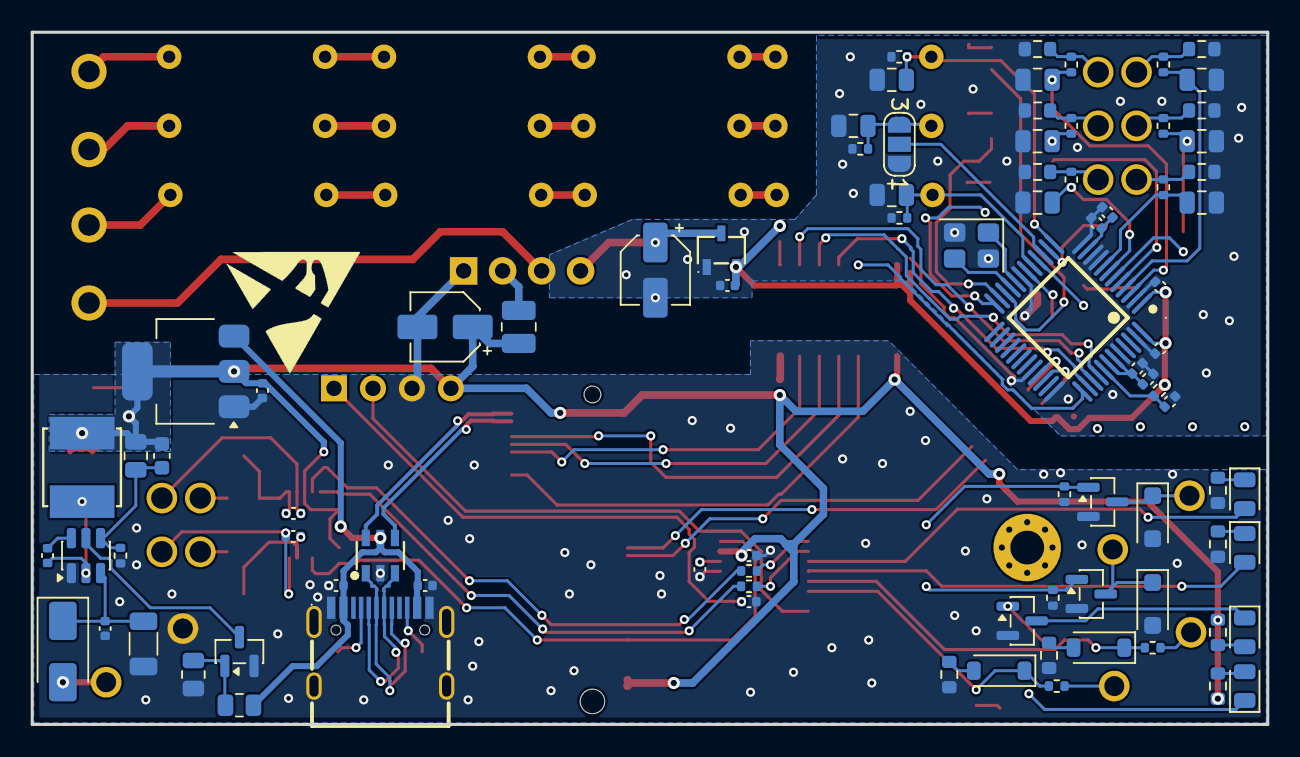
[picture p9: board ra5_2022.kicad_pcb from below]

Board: 2 copper layers, 80.5 x 45.1 mm, 153 parts (86 on the bottom side), 114 nets.

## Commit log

2026-07-20 Initial commit: RA5 2022 KiCad project
    [power_source.kicad_sch, ra5_2022.kicad_pcb, ra5_2022.kicad_sch]
2026-07-24 Add MCU and M90E32AS sheets, import connector/switch/MCU parts
    Adds the mcu.kicad_sch and m90e32as.kicad_sch hierarchical sheets and
    wires them into the root schematic and PCB. Imports several LCSC parts
    into the project-local ra5_2022 library (symbols/footprints/3D models):
    USB-C connectors, TQFP-48 MCU footprint, tactile switch, and the
    DB126V-5.0-2P terminal block, plus adds schematic-only symbols for the
    MX15EDGRHC-3.5-2x03P receptacle and its MX15EDGKNH-3.5-2x03P mating
    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
    [m90e32as.kicad_sch, mcu.kicad_sch, power_source.kicad_sch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]
2026-07-24 Ignore KiCad lock files and local restore-backup snapshots
2026-07-24 Add MX15EDGRHC-3.5-2x03P footprint and update M90E32AS connector
    Adds the new project-local footprint and repoints the M90E32AS
    6-pin connector to it, plus resulting PCB layout and project
    metadata updates.
    [m90e32as.kicad_sch, ra5_2022.kicad_pcb]
2026-07-27 Import B0303S-1WR2 (C7598619) LCSC component
    Add symbol, footprint, and 3D model for the B0303S-1WR2 isolated
    power module to the ra5_2022 project library.
2026-07-30 Import CS817x20LS (C5561839) digital isolator component
    Low-power dual-channel unidirectional isolator (Chipanalog), default-low
    fail-safe output, for isolating PM0/PM1 mode-select lines to the M90E32AS
    across the metering isolation barrier.
2026-07-30 Checkpoint: MCU/M90E32AS/power_source rework, PCB layout, new sheets, library imports
    - Rework mcu.kicad_sch, m90e32as.kicad_sch and power_source.kicad_sch: PM0/PM1/
    IRQ0/IRQ1 isolation wiring for the M90E32AS, USB-C native USB wiring, and
    related connector updates.
    - Add analog_io.kicad_sch and digital_io.kicad_sch hierarchical sheets.
    - Update ra5_2022.kicad_pcb layout and ra5_2022.kicad_pro settings.
    - Import several LCSC components into the project library (connectors,
    inductor, SOT/SOIC footprints, USB-C connectors, power module).
    - Fix import_lcsc_component.sh to normalize the "LCSC Part" field name to
    "LCSC Part #" on imported footprints too (previously only on symbols).
    - Ign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
    [analog_io.kicad_sch, digital_io.kicad_sch, m90e32as.kicad_sch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]
2026-07-30 Swap U7 isolator from ISO7742N1-Y to CS817X20LS
    Only PM0/PM1 need to cross the M90E32AS isolation barrier now (IRQ0/IRQ1
    dropped in favor of freeing GPIOs for the 4G modem RTS/CTS), so the
    4-channel 2fwd/2rev isolator is replaced with the 2-channel, same-direction,
    default-LOW CS817X20LS. Updates schematic, PCB footprint/routing and BOM.
    [mcu.kicad_sch, power_source.kicad_sch, ra5_2022.csv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]
2026-07-30 Import M.2 connector AS0BC21-S40BE-7H (C410527)
    Foxconn M.2 edgeboard connector, for the board-to-board sensor <-> MCU/modem
    link discussed for the RA5 2044 split-board topology.
2026-08-03 Checkpoint: RA5 base board finished, M.2 shield interconnect defined
    Base board (ra5_2022):
    - Finalize component placement on ra5_2022.kicad_pcb; next step is routing
    - Add STM8S003F3P to bridge the 2 digital inputs / 2 digital outputs onto
    the shared I2C bus (alongside the ADS1115), freeing up M.2 pins
    - Wire J1 (M.2 Key-E) to a custom, non-spec-compliant 3.3V pinout: I2C
    (SDA/SCL/ALERT#) on the native pins, M90E32AS SPI reusing the SD/SDIO
    "SPI mode" pin convention (SCLK/MOSI/MISO/CS), PM0/PM1 on VENDOR_DEFINED
    pins, USB-C passthrough, full GND/VDD
    - Fix AS0BC21-S40BE-7H footprint: pads 76/77 (shield/ground tabs, not part
    of the 75-pin M.2 spec) remapped onto the GND pin instead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
    [analog_io.kicad_sch, digital_io.kicad_sch, m90e32as.kicad_sch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]
2026-08-05 Fix USB_90R/HighSpeed netclass clearance for M.2 socket pitch, route USB diff pair, add board render doc
    Netclass clearance (0.25mm) exceeded the J1 M.2 socket's actual 0.5mm-pitch
    pad spacing (~0.2mm) and the USB_90R diff pair gap (0.1mm), blocking the
    interactive router from escaping J1's pads. Lowered USB_90R and HighSpeed
    clearance to 0.2mm and the board's global min_clearance/min_connection to
    match, plus a custom rule permitting the 0.1mm DP/DN internal gap. Routed
    the USB_DP/USB_DN differential pair from J1 to D3.
    Added view/ with finished-board renders and a short board description.
    [mcu.kicad_sch, ra5_2022.kicad_pcb]
2026-08-05 Move board render doc to root README so it shows on the repo's main page
    Keeps the images under view/, README now referencing view/view1.png and
    view/view2.png instead of relative paths.
2026-08-07 Migra componentes das bibliotecas LCSC locais para pecas JLCPCB
    Troca os part numbers para casar com o estoque da JLCPCB e com o
    catalogo PCBA Basic, eliminando a biblioteca local que era importada
    via easyeda2kicad.
    - Remove libraries/ (simbolos, footprints e modelos 3D importados) e o
    script import_lcsc_component.sh
    - Adiciona o plugin JLCPCB (jlcpcb/project.db) e os scripts auxiliares
    fix_jlcpcb_tools_deps.sh e generate_ibom.sh
    - Atualiza as cinco folhas do esquematico, o PCB e as regras de projeto
    O PCB fica em estado intermediario: os componentes novos ainda precisam
    ser reposicionados e as trilhas refeitas.
    [analog_io.kicad_sch, digital_io.kicad_sch, m90e32as.kicad_sch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]
2026-08-11 Remove ra5_shield_modem (moved to its own repo), translate README to English
    The MCU+modem shield card is now developed as a fully separate project
    rather than a sibling directory here. Rewrites the base-board README in
    English with a component list verified against the current schematics,
    and updates CLAUDE.md's architecture/library-sharing notes to match.
    [ra5_shield_modem.kicad_pcb, ra5_shield_modem.kicad_sch]
2026-08-11 Reintroduz biblioteca local ra5_2022 e atualiza layout/esquematicos
    Volta a usar simbolos, footprints e modelos 3D importados via
    easyeda2kicad (libraries/) em vez das pecas basicas JLCPCB adotadas no
    commit anterior, alem de atualizar o roteamento/posicionamento no PCB
    e as cinco folhas do esquematico.
    [analog_io.kicad_sch, m90e32as.kicad_sch, mcu.kicad_sch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]
